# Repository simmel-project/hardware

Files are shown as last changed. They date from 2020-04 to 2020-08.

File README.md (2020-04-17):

# Simmel Hardware Reference Design

This repository tracks the latest releases of the Simmel hardware reference design.

Currently, the design is at an EVT stage, which means, we're trying to figure out if this thing even works. Furthermore, the mechanical design is more of a concept, there are several key details that still need resolution, including the ultrasound port design and the top battery contact-to-PCB interface. Please be aware!

The repository is broadly structured into electrical and mechanical artifacts. The electrical artifacts include the schematic and PCB design. The mechanical artifacts include the case design and drawings. 

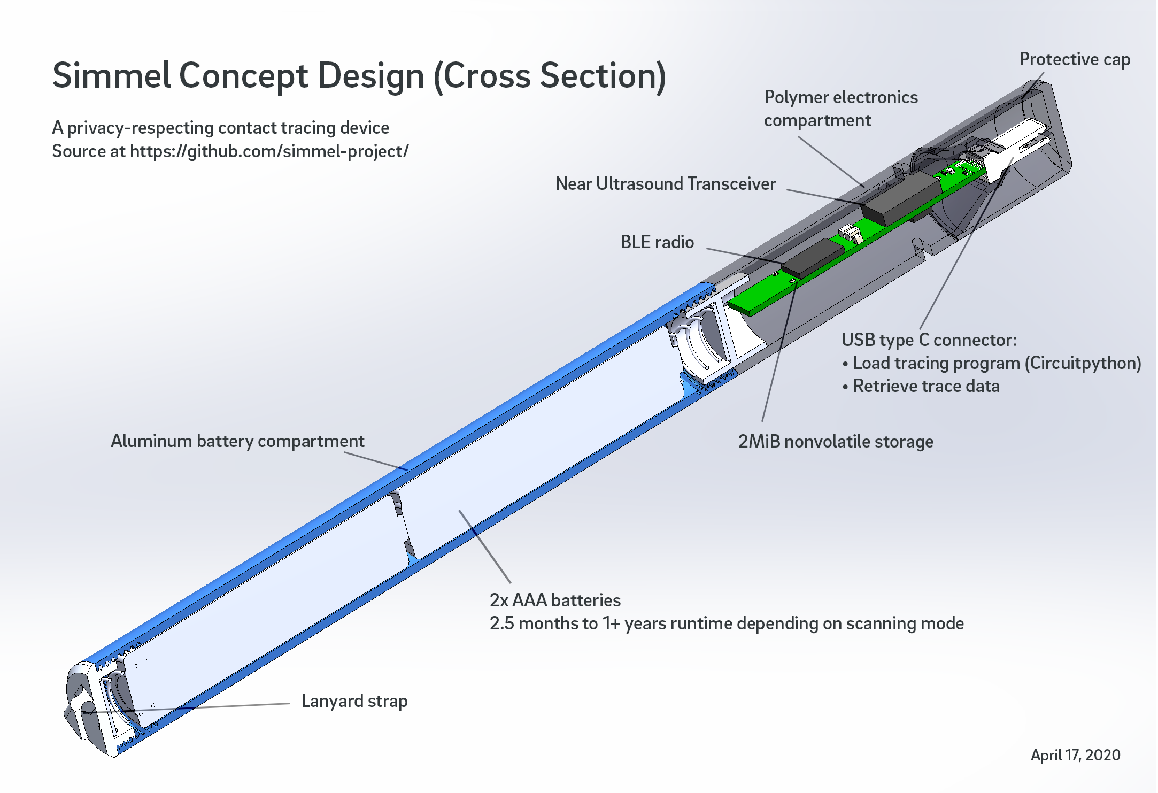
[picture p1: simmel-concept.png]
simmel cross section diagram


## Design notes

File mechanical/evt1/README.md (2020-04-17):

# Simmel EVT1 Mechanical Design

This is a conceptual design for the Simmel device. Many assumptions are baked into
this design, many of which can be easily changed or varied. For example, the number
and type of batteries, as well as the connector type are subject to change. Furthermore,
important details such as the ultrasound acoustic ports and the positive battery contact
assembly are still in the process of research and finalization. 

However, this concept serves a reasonable starting point for discussion and ideation
about the Simmel hardware integration. 

STEP is a "neutral" 3D mechanical file interchange format. You may view and edit it
with a program such as [FreeCAD](https://www.freecadweb.org/). The PDF file provides additional
annotation about the function and role of the various elements in the design.

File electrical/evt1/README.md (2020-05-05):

# Electrical Reference for Simmel (EVT)

Here are files for a very preliminary version of the Simmel hardware. It probably
won't catch fire, but it also probably doesn't work as advertised. But that's
what prototypes are for!

The Altium files may be imported into KiCAD using [AtoK](https://github.com/stevegrn/AtoK).

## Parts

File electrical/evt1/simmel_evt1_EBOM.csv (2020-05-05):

Comment | Description | Designator | Footprint | LibRef | Quantity | MPN | MYPN | VENDOR
4.7uF, 10V, X7S | Capacitor (Semiconductor SIM Model) | C1, C2, C21, C22, C23, C25 | B_CAP0603 | Cap Semi | 6 | ?C1608X7S1A475K080AC? | C-475-10-X7S-0603 | TDK
1.0uF, 6.3V, X5R | Capacitor (Semiconductor SIM Model) | C3, C4, C7, C12 | B_CAP0201 | Cap Semi | 4 | GRM033R60J105MEA2D | C-105-6p3-X5R-0201 | Murata
0.1uF, 6.3V, X5R | Capacitor (Semiconductor SIM Model) | C5, C9, C11, C15, C16, C24, C26 | B_CAP0201 | Cap Semi | 7 | CL03A104KQ3NNNC | C-104-6p3-X5R-0201 | Samsung
12pF, NP0 | Capacitor (Semiconductor SIM Model) | C6, C10, C14, C17 | B_CAP0201 | Cap Semi | 4 | GRM0335C1E120JA01D | C-120-25-NP0-0201 | Murata
0.047uF 6.3V X5R | Capacitor (Semiconductor SIM Model) | C8 | B_CAP0201 | Cap Semi | 1 | GRM033C81A473KE05D | C-473-10-X6S-0201 | Murata
100pF, NP0 | Capacitor (Semiconductor SIM Model) | C13 | B_CAP0201 | Cap Semi | 1 | ?CC0201JRNPO8BN101? | C-101-25-NP0-0201 | Murata
1.0pF, NP0 | Capacitor (Semiconductor SIM Model) | C18 | B_CAP0201 | Cap Semi | 1 | GJM0335C1E1R0CB01D? | C-1R0-25-NP0-0201 | Murata
1.2pF, NP0 | Capacitor (Semiconductor SIM Model) | C19 | B_CAP0201 | Cap Semi | 1 | ?GRM0335C1H1R2CA01D? | C-1R2-50-NP0-0201 | Murata
820pF, NP0 | Capacitor (Semiconductor SIM Model) | C20 | B_CAP0201 | Cap Semi | 1 | TMK063CG821JT-F? | C-821-25-NP0-0201 | Tayo Yuden
PESD5V0H1BSF | ESD7331MUT5G | D1 | D_X3DFN2_0201 | D Zener | 1 | PESD5V0H1BSF | D-PESD5V0H1BSF | Nexperia
ESD7331MUT5G | ESD7331MUT5G | D2, D3 | D_X3DFN2_0201 | D Zener | 2 | ESD7331MUT5G | D-ESD7331MUT5G | ON Semi
white LED | Red LED | D4 | B_DIO0402 | LED2 | 1 | EAST10052WA0 | D-LED-WHT-0402 | Everlight
power tap (DNP) | Connector | J1 | RESTAP-0603 | CON1 | 1 | DNP | J-TP-PWRTAP-0603 | DNP
15nH | High frequency chip inductor ±10% | L1 | B_CAP0201 | L0402-15n | 1 | ?LQP03TN15NH02D? | L-?LQP03TN15NH02D? | Murata
10uH | Chip inductor, IDC,min = 50 mA, ±20% | L2 | B_IND0603 | L0603-10µ-TDK | 1 | ?LQM18FN100M00D? | L-?LQM18FN100M00D? | Murata
4.7nH | High frequency chip inductor ±5% | L3 | B_CAP0201 | L0402-4n7 | 1 | ?LQP03TN4N7H02D? | L-?LQP03TN4N7H02D? | Murata
2.2nH | High frequency chip inductor ±5% | L4 | B_CAP0201 | L0402-2n2 | 1 | ?LQP03TN2N2B02D? | L-?LQP03TN2N2B02D? | Murata
CPT-1117-83-SMT-TR | 11 mm, 5 Vp-p, 83 dB, Surface Mount _SMT_, Piezo Audio Transducer Buzzer | LS | XDCR_CPT-1117-83-SMT-TR | CPT-1117-83-SMT-TR | 1 | CPT-1117-83-SMT-TR | SPK-CPT-1117-83-SMT-TR | CUI Devices
PKMCS0909E4000-R1 | 11 mm, 5 Vp-p, 83 dB, Surface Mount _SMT_, Piezo Audio Transducer Buzzer | LS1 | MURATA_PKMCS0909E4000-R1 | CPT-1117-83-SMT-TR | 1 | PKMCS0909E4000-R1 | SPK-PKMCS0909E4000-R1 | Murata
ANT 2.5GHz | Header, 2-Pin | P1 | B_RES0603 | Header 2 | 1 | ?2450AT14A0100T? | Y-?2450AT14A0100T? | Johanson Technology
FPC | Header, 6-Pin | P2 | HRS_FH34SRJ-6S-0.5SH(50) | Header 6 | 1 | FH34SRJ-6S-0.5SH(50) | J-FH34SRJ-6S-0.5SH(50) | HRS
USB Type C Male Connector | USB Type C Connector | P3 | MOLEX_1054440001 | USB_TYPE_C | 1 | 1054440001 | P-1054440001 | Molex
PMZB670UPE | P-Channel MOSFET | Q1, Q3 | SOT883 | MOSFET-P | 2 | PMZB670UPE | Q-PMZB670UPE | Nexperia
PMZ290UNE2 | N-Channel MOSFET | Q2, Q4, Q5 | SOT883 | MOSFET-N | 3 | PMZ290UNE2 | Q-PMZ290UNE2 | Nexperia
100k, 1% | Resistor | R1, R9 | B_RES0201 | Res1 | 2 | ANY | R-104-1P-1_16W-0201 | ANY
470, 1% | Resistor | R2, R4, R10 | B_RES0201 | Res1 | 3 | ANY | R-471-1P-1_16W-0201 | ANY
8.06k, 1% | Resistor | R3 | B_RES0201 | Res1 | 1 | ANY | R-8061-1P-1_16W-0201 | ANY
10, 1% | Resistor | R5 | B_RES0402 | Res1 | 1 | ANY | R-100-1P-1_16W-0402 | ANY
DNP | Resistor | R6 | B_RES0201 | Res1 | 1 | ANY | DNP | ANY
5.1k, 1% | Resistor | R7, R8 | B_RES0201 | Res1 | 2 | ANY | R-512-1P-1_16W-0201 | ANY
solder terminal (DNP) | Connector | TP1, TP2, TP3 | TP_SMT_1.5x1mm | CON1 | 3 | DNP | Built into PCB | DNP
solder terminal (DNP) | Connector | TP4, TP5 | TP_0.4x0.4_SMT | CON1 | 2 | DNP | Built into PCB | DNP
MCP73832T-2ACI/MC | Miniature Single-Cell, Fully Integrated Li-Ion, Li-Polymer Charge Management Controller | U1 | SON50P300X100_HS-9L | MCP73832T-2ACI/MC | 1 | MCP73832T-2ACI/MC | U-MCP73832T-2ACI/MC | Microchip
MX25R1635FZUIL0 | 64Mbit SPI NOR FLASH | U2 | USON-8 | EN25P05-50GCP | 1 | MX25R1635FZUIL0 | U-MX25R1635FZUIL0 | Macronix
ICS-43434 | Digital I2S microphone | U3 | INVENSENSE_ICS_43434 | ICS-43434 | 1 | ICS-43434 | MIC-ICS-43434 | TDK InvenSense
NRF52833QIAA | BLE plus NFC and USB | U4 | NORDIC_AQFN_7X7_73 | NRF52833QIAA | 1 | NRF52833QIAA | U-NRF52833QIAA | Nordic
32MHz 8pF 10ppm | XTAL SMD 2016, 32MHz, Cl=8pF, Total Tol: ±40ppm | X1 | XTAL_20X16 | XTAL_SMD2016_32MHz_8pF_General | 1 | NX2016SA-32MHZ-EXS00A-CS11336 | Y-NX2016SA-32MHZ-EXS00A-CS11336 | NDK
32.768kHz, 9pF 20ppm | XTAL SMD 3215, 32.768kHz, Cl=9pF, Total Tol: ±50ppm | X2 | XTAL_3215 | XTAL_SMD3215_32.768kHz_9pF_General | 1 | RT3215-32.768-9-TR | Y-RT3215-32.768-9-TR | Raltron Electronics

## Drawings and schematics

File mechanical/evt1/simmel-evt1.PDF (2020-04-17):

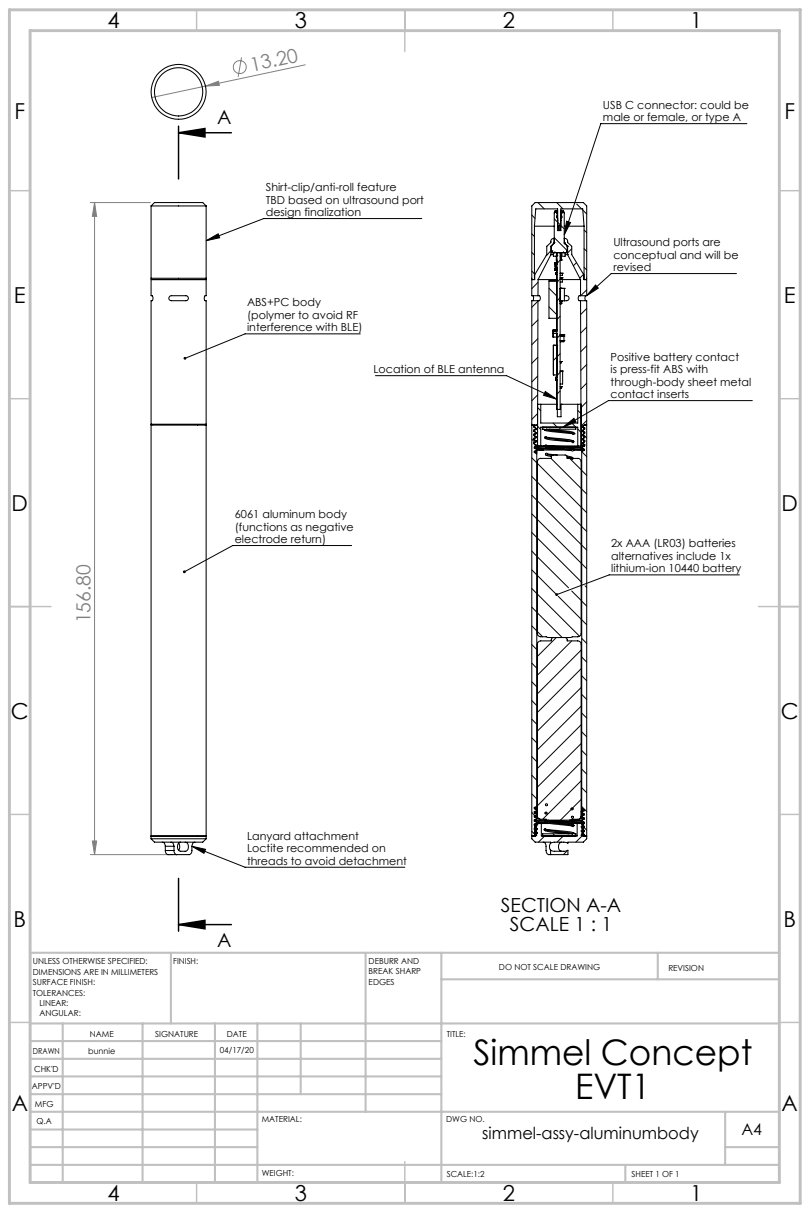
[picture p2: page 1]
SECTION A-A SCALE 1 : 1; FINISH:; DEBURR AND; BREAK SHARP; DO NOT SCALE DRAWING; REVISION; SCALE:1:2; SHEET 1 OF 1

USB C connector: could be
male or female, or type A

Shirt-clip/anti-roll feature
TBD based on ultrasound port
design finalization

Ultrasound ports are
conceptual and will be
revised

ABS+PC body
(polymer to avoid RF
interference with BLE)

Positive battery contact
is press-fit ABS with
through-body sheet metal
contact inserts

Location of BLE antenna

6061 aluminum body
(functions as negative
electrode return)

2x AAA (LR03) batteries
alternatives include 1x
lithium-ion 10440 battery

Lanyard attachment
Loctite recommended on
threads to avoid detachment

UNLESS OTHERWISE SPECIFIED:
DIMENSIONS ARE IN MILLIMETERS
SURFACE FINISH:
TOLERANCES:
LINEAR:
ANGULAR:

NAME | SIGNATURE | DATE | | | | TITLE: Simmel Concept EVT1

DRAWN | bunnie | | 04/17/20
CHK'D
APPV'D
MFG
Q.A | | | | MATERIAL: | DWG NO. simmel-assy-aluminumbody | A4

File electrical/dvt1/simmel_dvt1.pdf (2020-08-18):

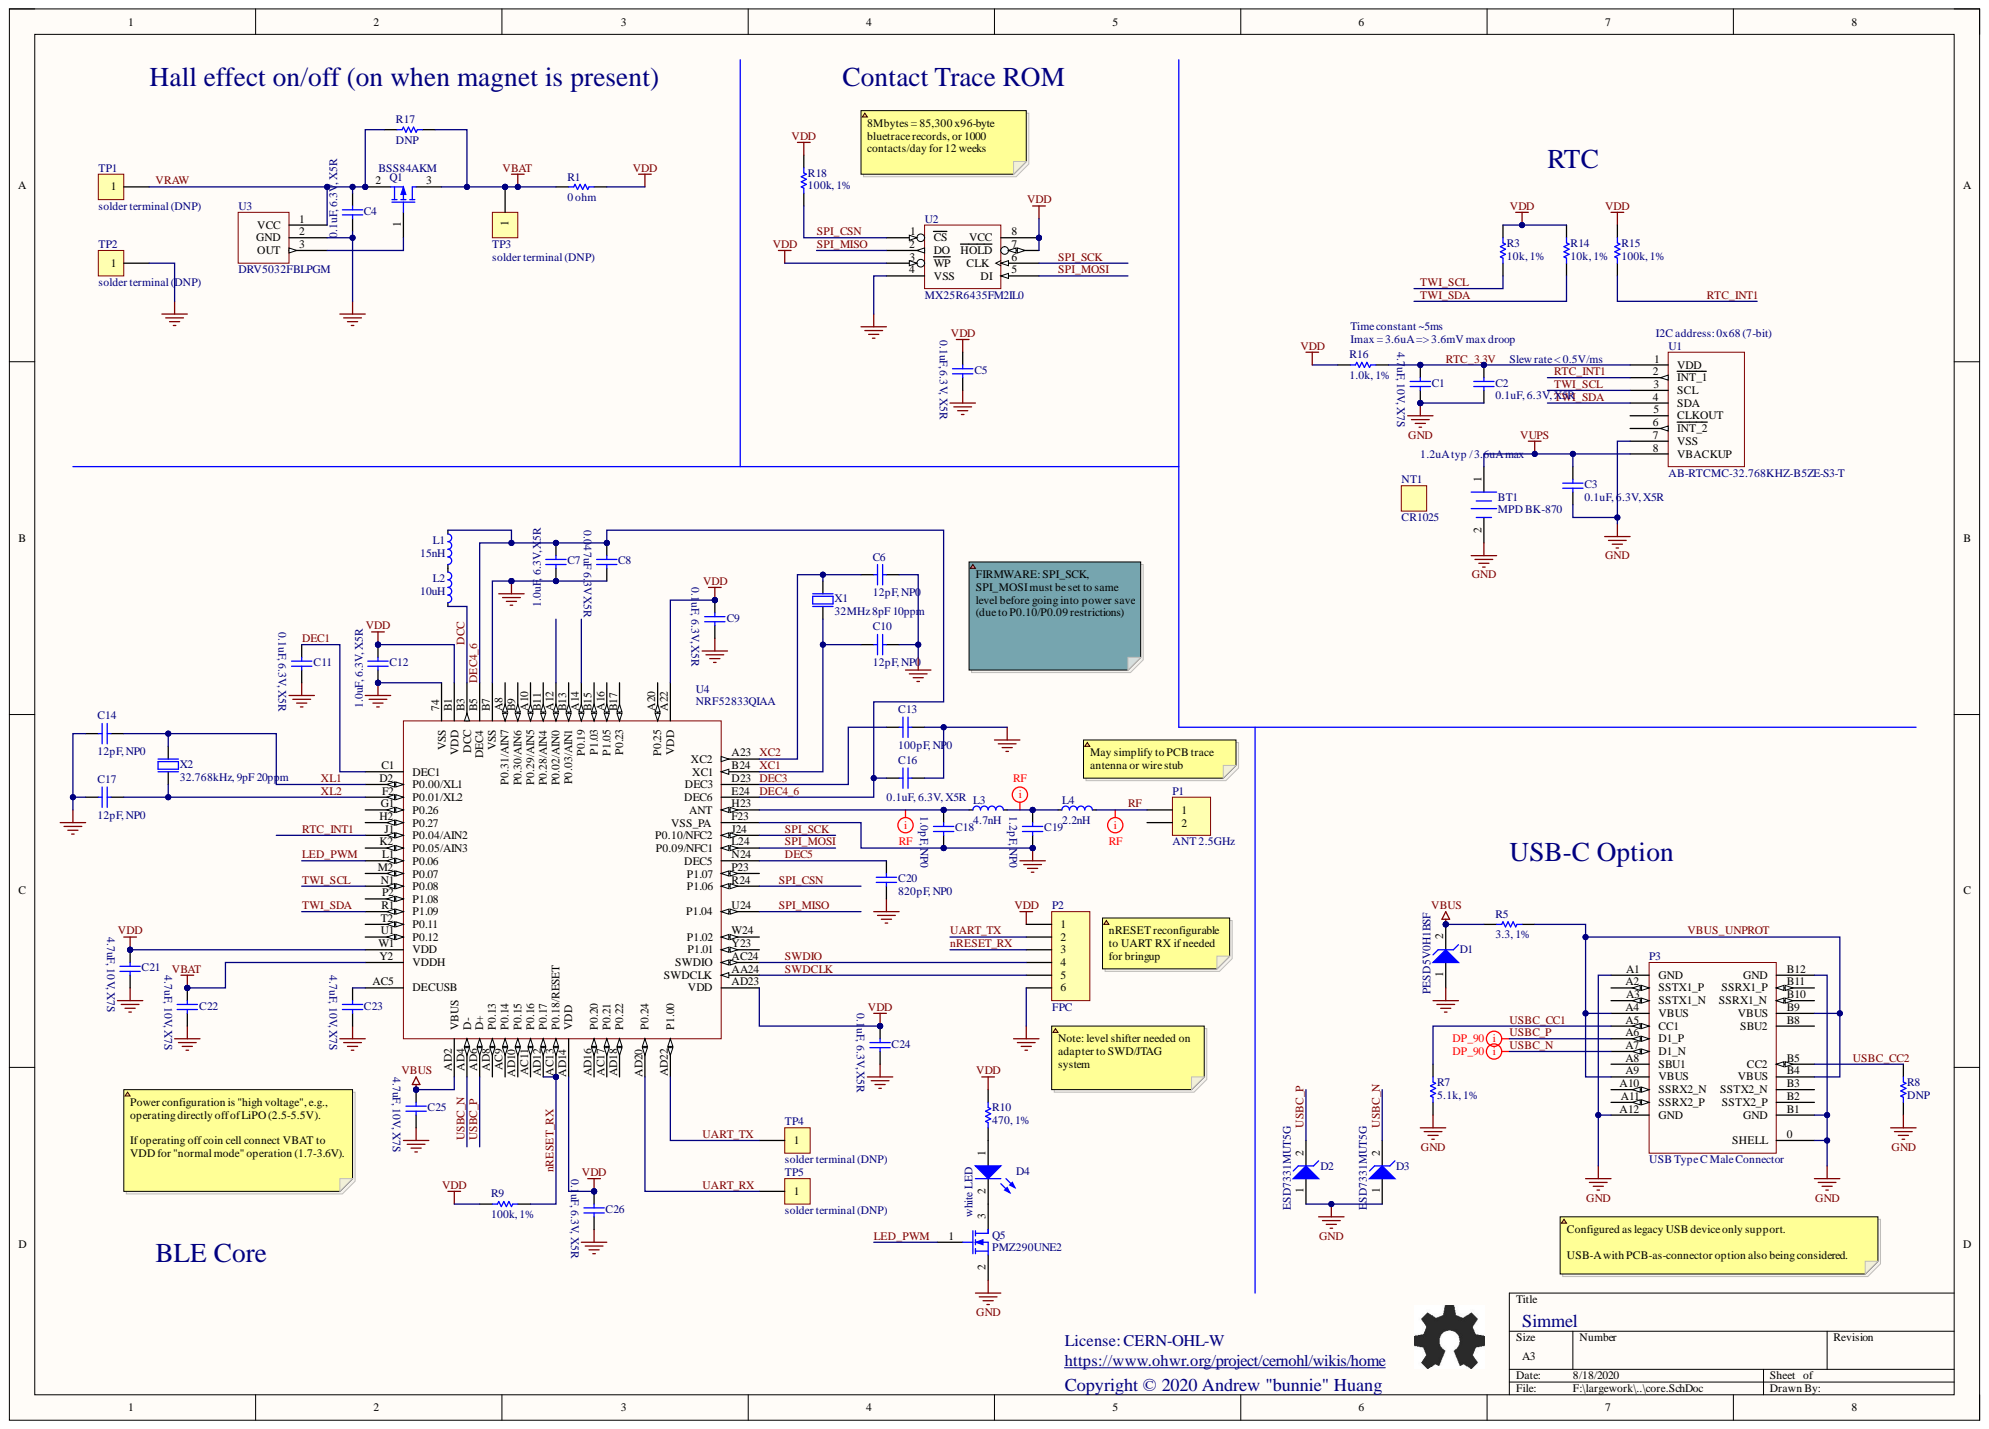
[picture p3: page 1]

A4 | B 9
A 5 | | B 8

A 8
A 9 | B 4

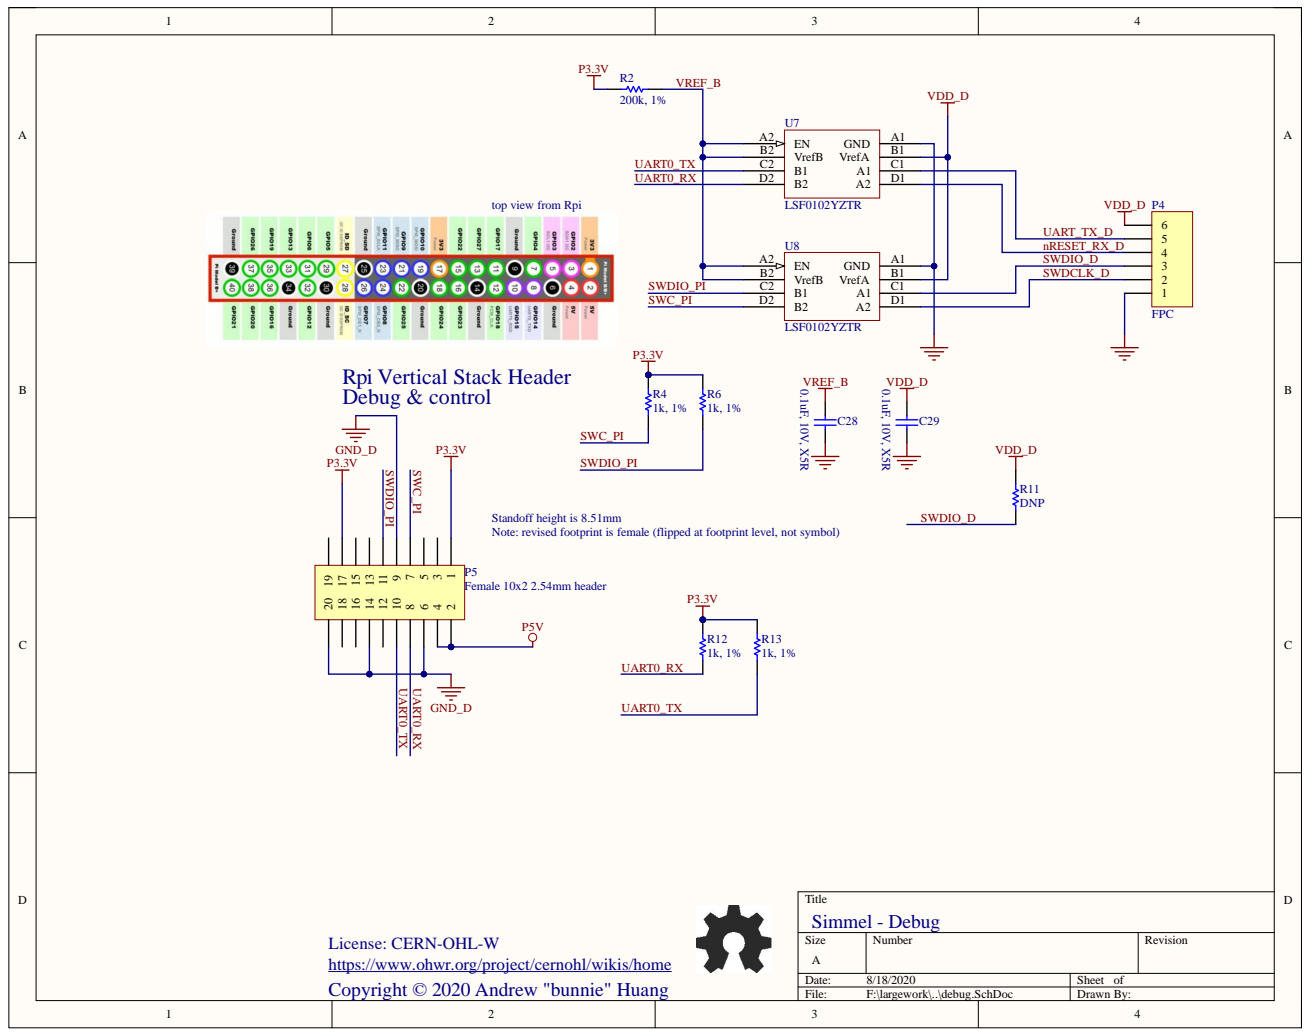
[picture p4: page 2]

top view from Rpi

UART_TX_D
nRESET_RX_D

Rpi Vertical Stack Header
Debug & control

Standoff height is 8.51mm
Note: revised footprint is female (flipped at footprint level, not symbol)

License: CERN-OHL-W
https://www.ohwr.org/project/cernohl/wikis/home
Copyright © 2020 Andrew "bunnie" Huang

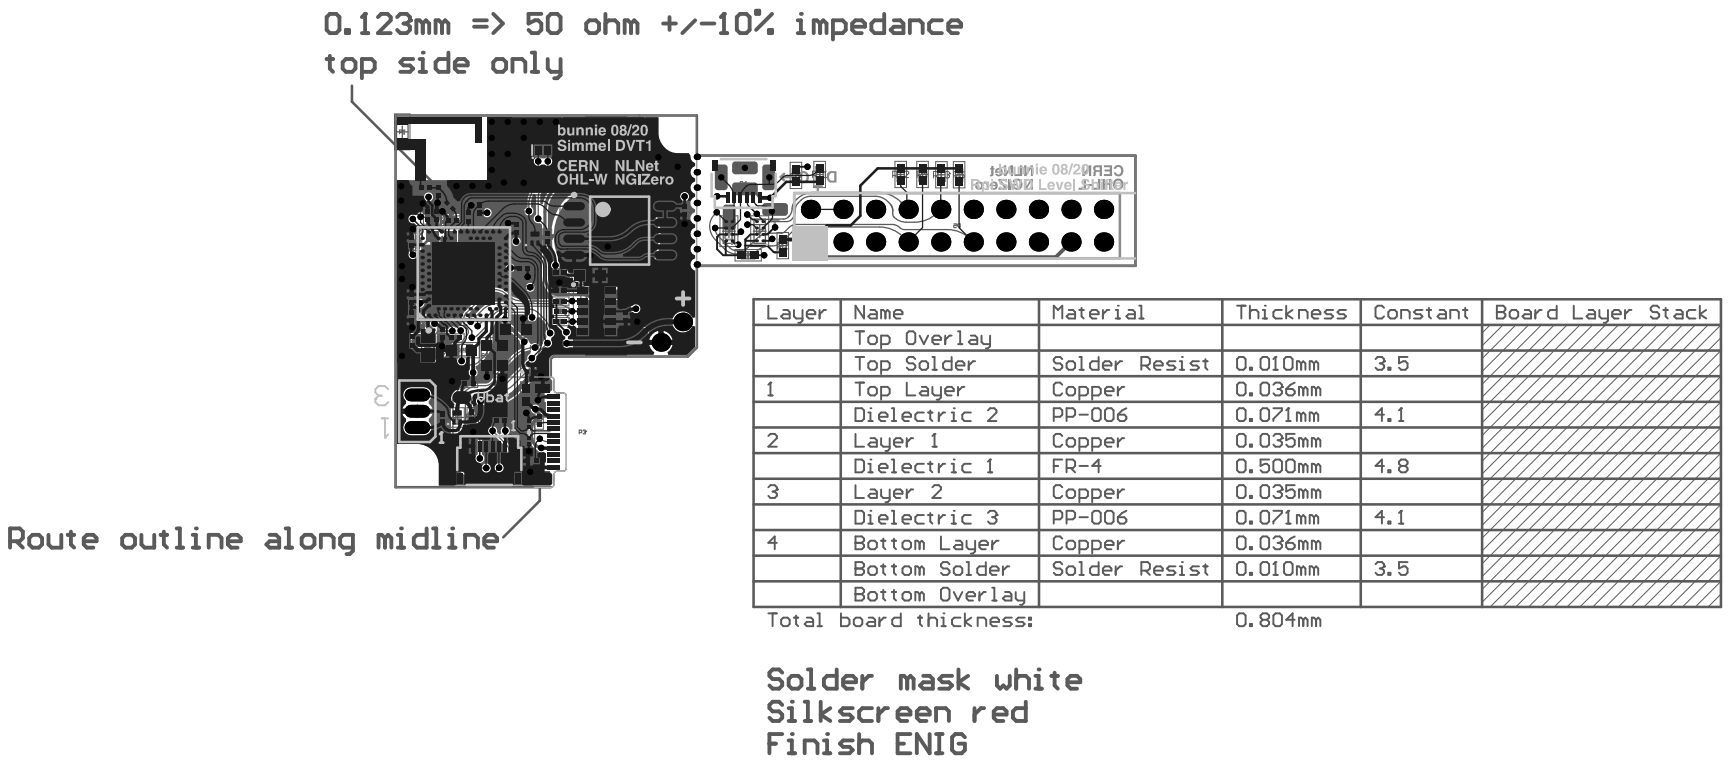
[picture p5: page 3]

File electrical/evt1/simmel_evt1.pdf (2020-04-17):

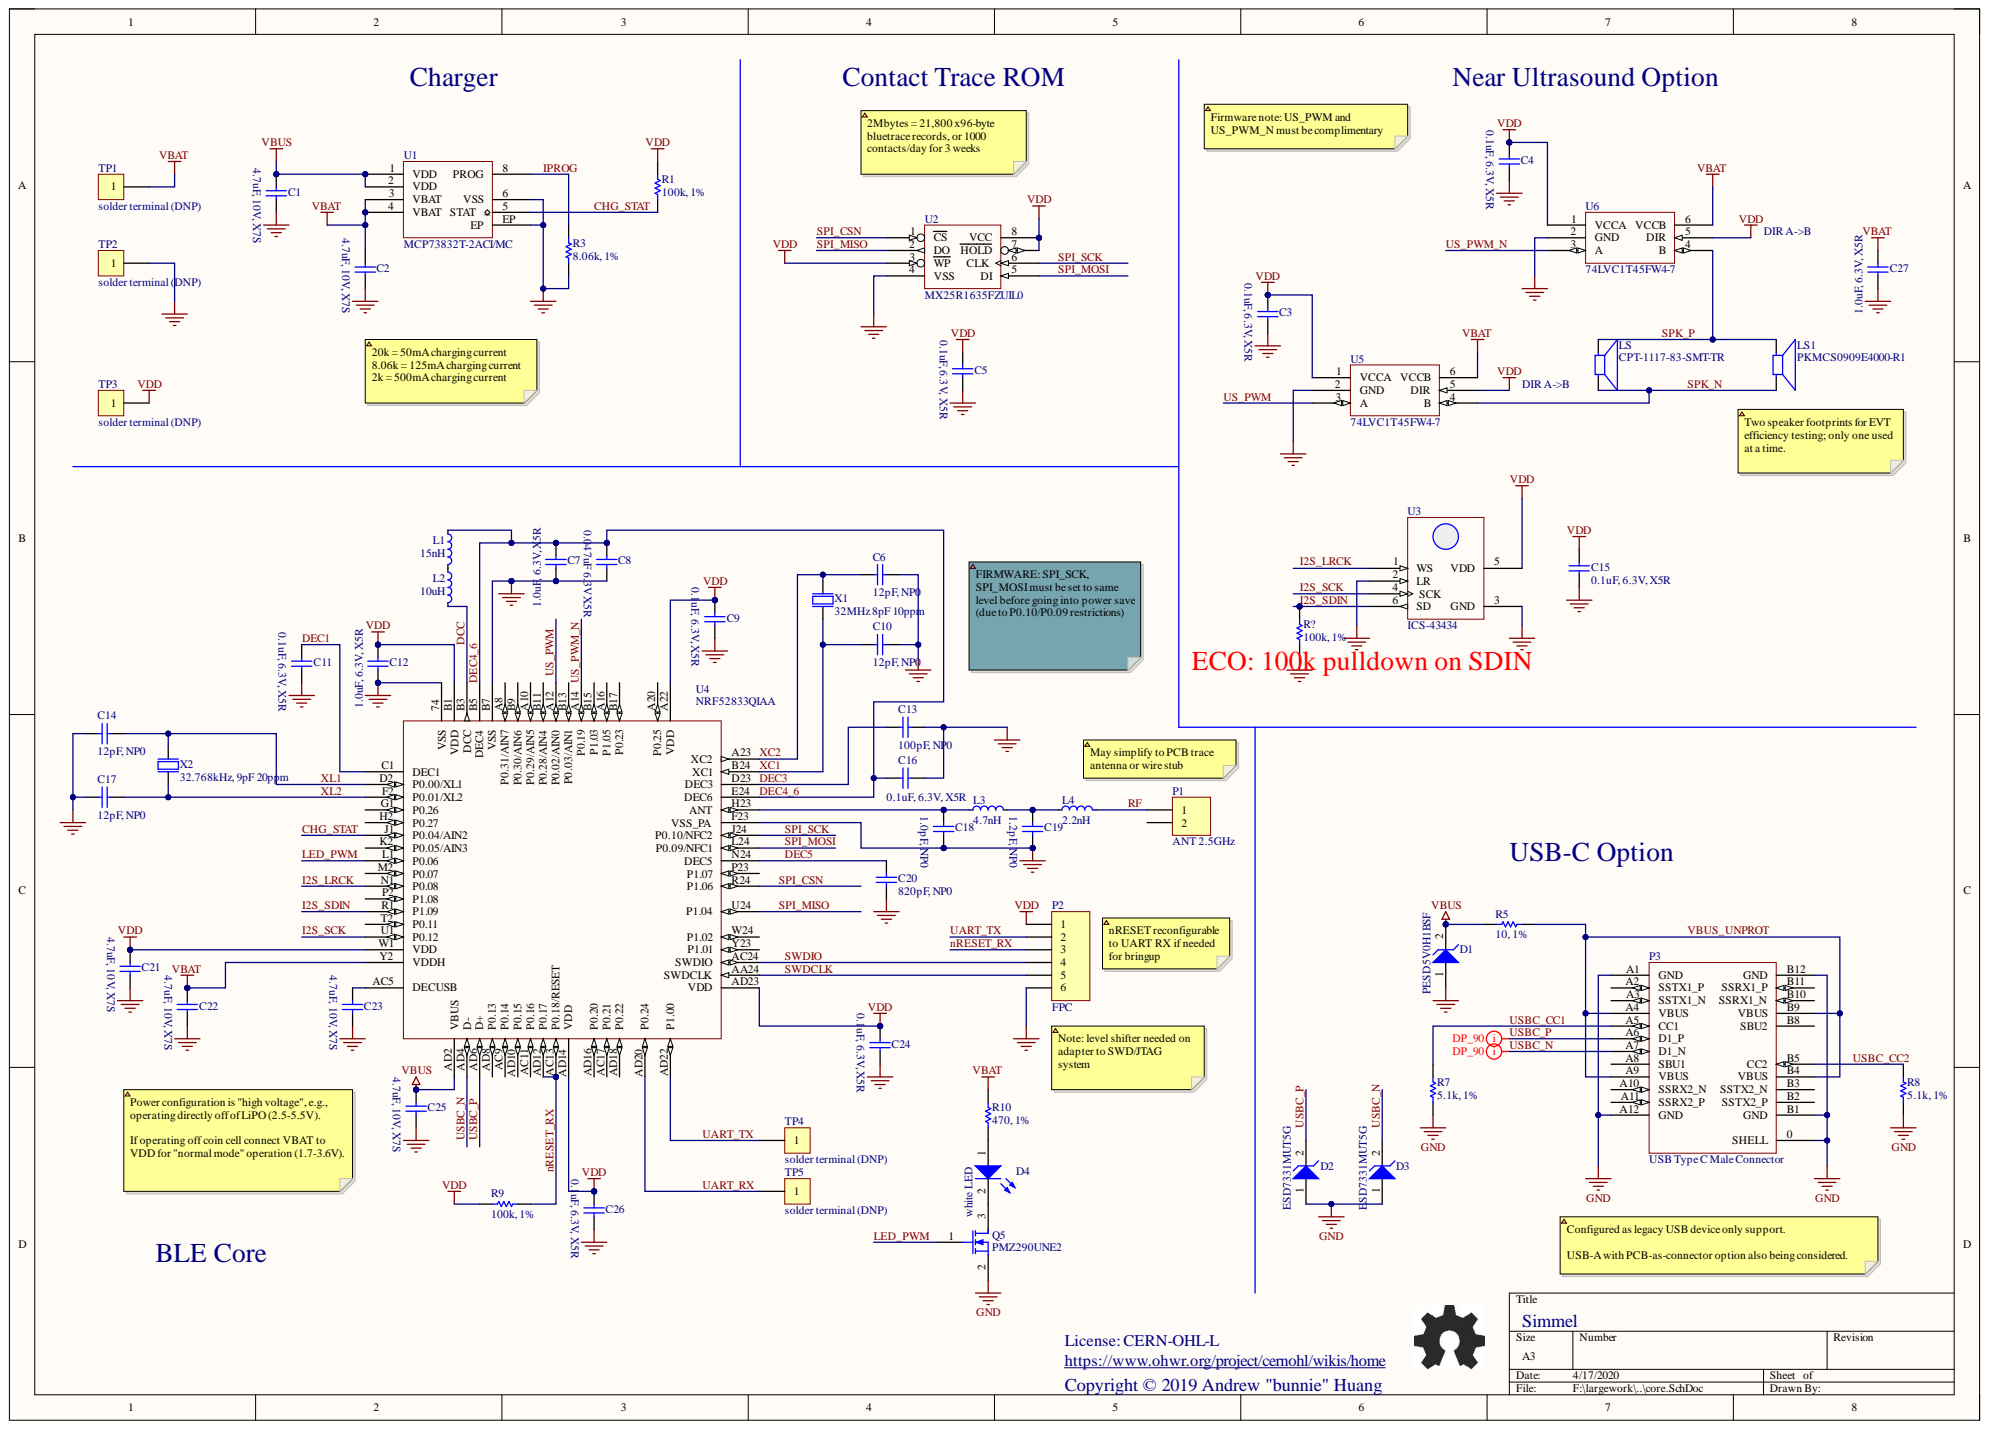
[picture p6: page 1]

2Mbytes = 21,800 x96-byte
bluetrace records, or 1000
contacts/day for 3 weeks

Two speaker footprintsfor EVT
efficiency testing; only one used
at a time.

FIRMWARE: SPI_SCK,
SPI_MOSImust be set to same
level before going into power save
(due to P0.10/P0.09 restrictions)

ECO: 100k pulldown on SDIN

May simplify to PCB trace
antenna or wire stub

nRESET reconfigurable
to UART RX if needed
for bringup

Note: level shifter needed on
adapter to SWD/JTAG
system

USBC_P DP_90 i USBC_N DP_90 i | D1_P A6

Power configuration is "high voltage", e.g.,
operating directly off ofLiPO (2.5-5.5V).

If operating off coin cell connect VBAT to
VDD for "normalmode" operation (1.7-3.6V).

Configured aslegacy USB device only support.

USB-Awith PCB-as-connector option also being considered.

License:CERN-OHL-L
https://www.ohwr.org/project/cernohl/wikis/home
Copyright © 2019 Andrew "bunnie" Huang

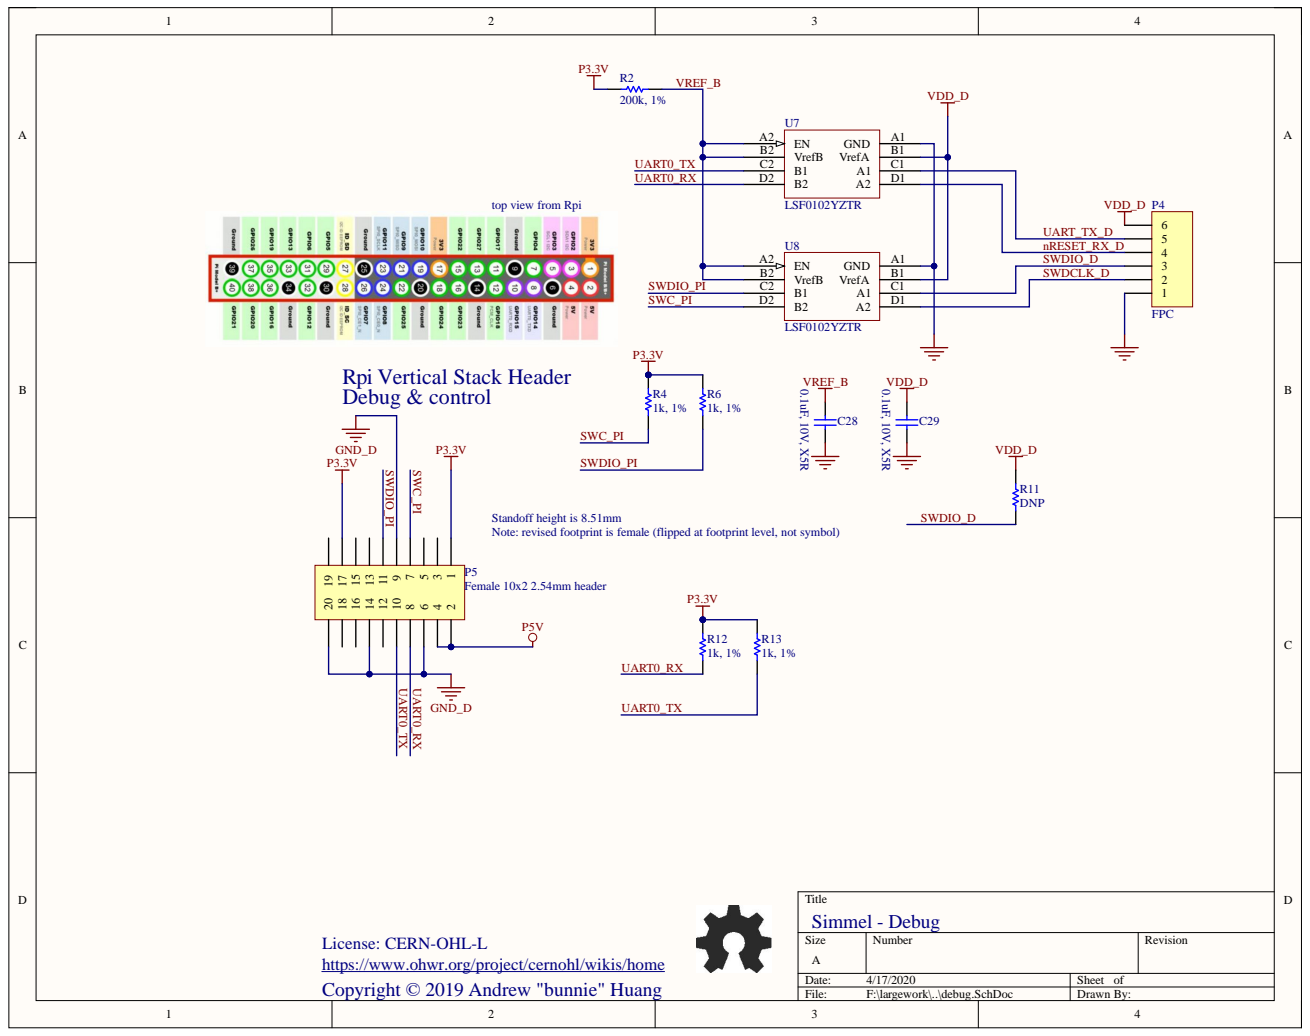
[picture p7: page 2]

top view from Rpi

UART_TX_D
nRESET_RX_D

Rpi Vertical Stack Header
Debug & control

Standoff height is 8.51mm
Note: revised footprint is female (flipped at footprint level, not symbol)

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

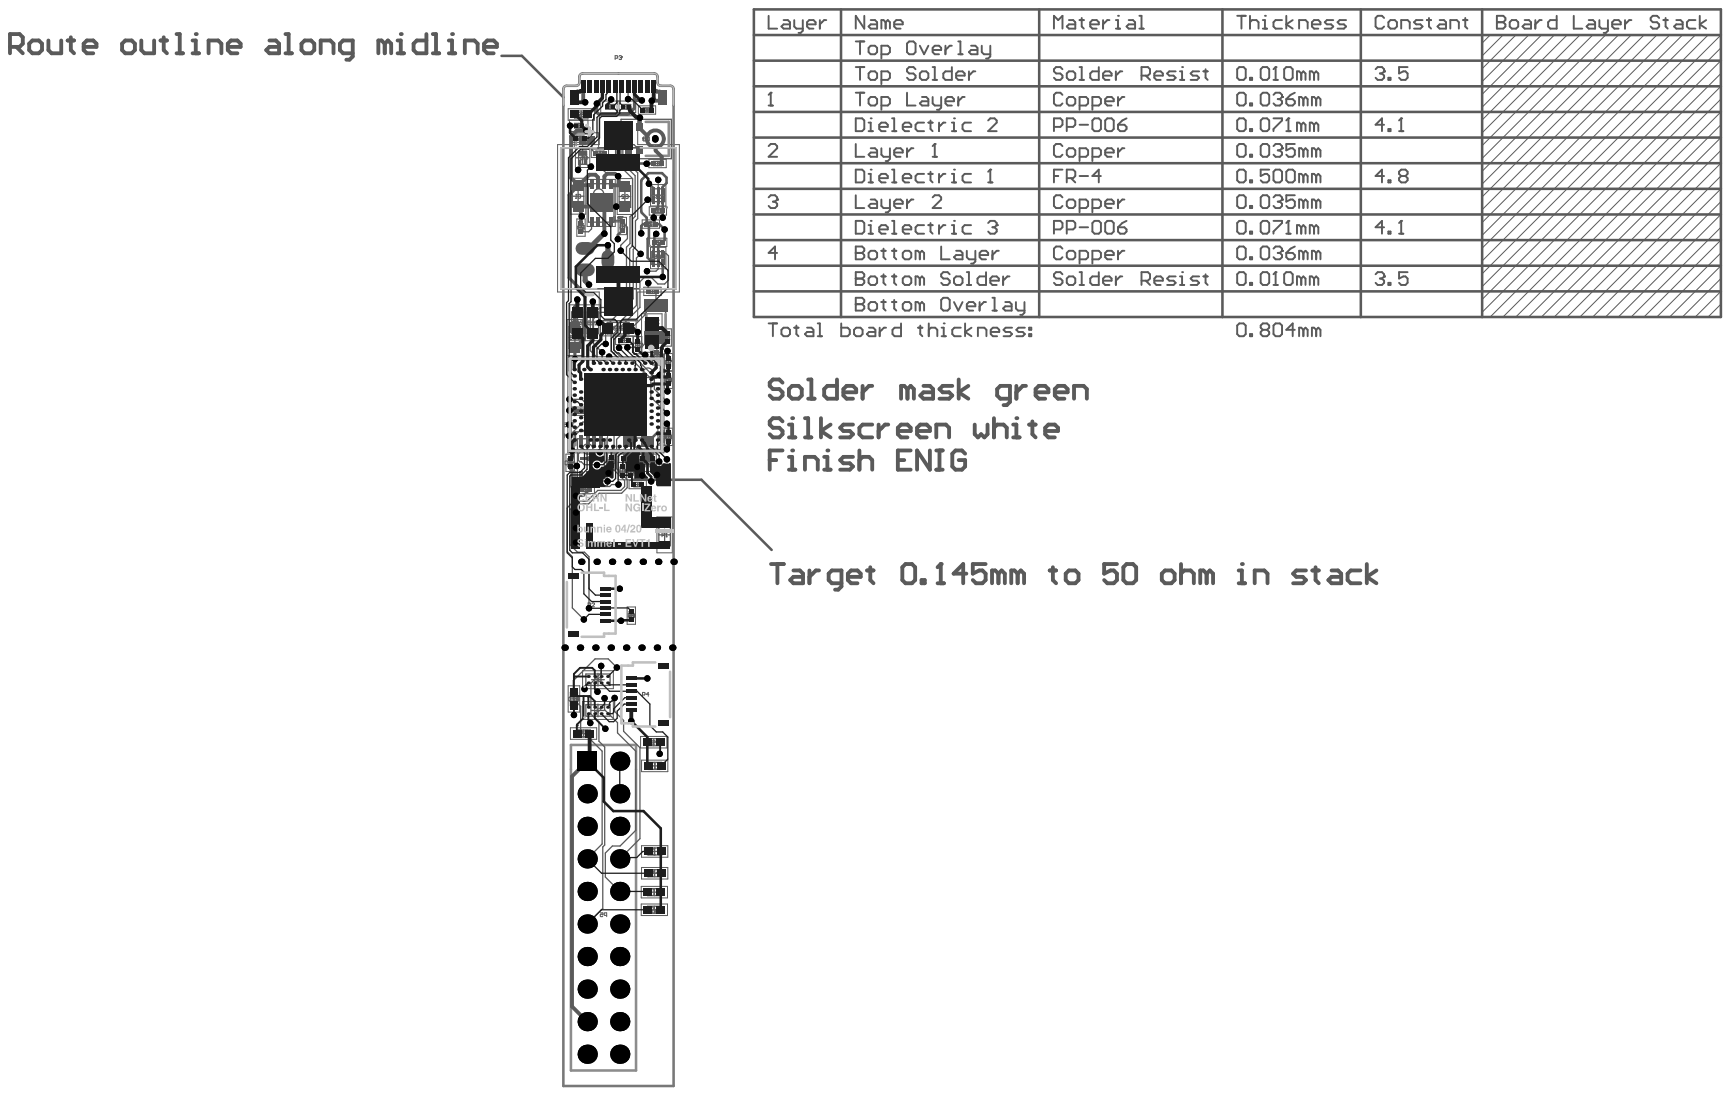
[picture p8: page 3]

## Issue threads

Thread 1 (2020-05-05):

Add Bill of Materials

xobs, 2020-05-05:
In order to know what type of components are needed, a BOM file should be added for Simmel EVT1.

bunnie, 2020-05-05:
e07debe4bb1786ced9818d6adfe71b2328fffacb adds the EBOM file.

Closed 2020-05-05.

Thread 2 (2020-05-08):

This is an awesome project!!

saewoonam, 2020-05-08:
A group of my colleagues have started something very similar:
https://github.com/saewoonam/ble_adv_covid

We started with BT dev boards to develop the software... And, we are now trying to build our own custom open-source hardware.   We should collaborate where it makes sense.   We are assembling a few prototypes now (~20) that we will try to field test with robots.

My colleagues and I are mostly in Boulder, CO.  But perhaps we could arrange a short web conference call.

We want to see an open-source inexpensive solution to encounter tracing to serve people who don't want to use their cell phone.  We think this could be a large set of people.

bunnie, 2020-05-09:
Hi! thanks for your interest. Our design is open source and you are welcome to use it!

Let us know if you have any specific questions or things you need help with!

saewoonam, 2020-05-09:
Ditto for you.  We are also making our design open source.   We haven't gone through and edited the licensing info yet...

I am curious about whether you have a strategy on whether you have decided on some kind of protocol for the ultrasonic signals?  We are in the middle of discussing adding this capability.

bunnie, 2020-05-09:
For the ultrasound, we plan on trying an FSK protocol first. We already have a version of it working (over a wire) in a product we did a while a go: https://github.com/chibitronics/ltc-os/blob/master/orchard/esplanade_demod.c

In full disclosure, the ultrasound feature was a request made by NLnet to include into our system; personally, I have skepticism around the physics of ultrasound propagation in real-world environments limiting the utility of this mechanism, but the general technique has sufficient upsides around privacy and power consumption that it's probably worth exploring despite the technical risk. At the very least, we'll get some hard facts around what can and can't be accomplished in a real-world setting. And at the very least, the system can do BLE, which will definitely work, but has some issues around privacy, power, and determinism around proximity.

Also, I wanted to call out that we're protocol-agnostic in our system -- our goal is to provide a concept platform that protocol implementers can use as a reference for their great ideas. It looks like you're also using Circuitpython, so it seems like it may be possible your protocol layer would also run on our hardware, which is great!

saewoonam, 2020-05-09:
Actually, we have been coding C because I wanted to try to fit the code on devices that can't support circuitpython and bluetooth at the same time... But, I would love to switch to circuit python... It would make coding much much easier.

xobs, 2020-05-09:
Our goal is to go the other way: Start out on Circuit Python, and then move to smaller devices if ultrasound proves the way to go.  As you say, it's easier to get started on.

We've been working with the Circuit Python project to [add Simmel support](https://adafruit-circuit-python.s3.amazonaws.com/index.html?prefix=bin/simmel/).  In particular, we have basic AES integrated, and we've been stabilising low power support.  The next (and potentially most architecturally difficult) module to integrate will be the I2S driver which will be used to read from the microphone.

saewoonam, 2020-05-09:
Did you choose I2S because it was simpler to interface... What about a PDM microphone?  It is simpler from a hardware but more complex on the signal processing side.  But, I have a gut feeling there may be clever algorithms to do FSK decoding.

saewoonam, 2020-05-09:
Anyway, this is awesome that you guys are working in this direction.  I have c-code working using Zephyr that integrates bluetooth advertising, scanning, and storing encounters to the flash (same chip as you are using).   You are welcome to use it, or I can help you port it to your device...

bunnie, 2020-05-09:
> Did you choose I2S because it was simpler to interface... What about a PDM microphone? It is simpler from a hardware but more complex on the signal processing side. But, I have a gut feeling there may be clever algorithms to do FSK decoding.

There's an I2S interface built into the NRF52833, so in theory this is one of the simpler ways to do it. Picked I2S because it bypasses a lot of thorny analog design issues around the mic (vs. going to an ADC input on the NRF). PDM could also work but since our part has a native I2S interface the actual hardware complexity is lower (although we do have to write an I2S driver, tbd how awful that is).

xemmanuel, 2020-06-12:
Hi guys, we work in the french StopCovid project:
https://www.linkedin.com/pulse/copsonic-join-stopcovid-task-force-tracing-french-app-emmanuel-ruiz/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

https://youtu.be/5IUrAio5AS4

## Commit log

2020-04-17 add EVT1 hardware design files
    [core.SchDoc, debug.SchDoc, simmel_evt1.PrjPcb]
2020-05-05 add a bom file
    [simmel_evt1_EBOM.csv]
2020-08-18 add simmel DVT design files
    physical form factor and feature compatibility with
    the Singapore TraceTogether token
    [core.SchDoc, debug.SchDoc, simmel_dvt1.PrjPcb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]
2020-08-18 update license from CERN OHL-L to CERN OHL-W
    seems the naming was changed and we never got the memo.
    [core.SchDoc, debug.SchDoc, simmel_full_dvt1.PcbDoc]
